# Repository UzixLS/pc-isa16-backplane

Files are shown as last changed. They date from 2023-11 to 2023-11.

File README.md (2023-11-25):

## ISA16-BACKPLANE
Compact ISA 16-bit backplane board

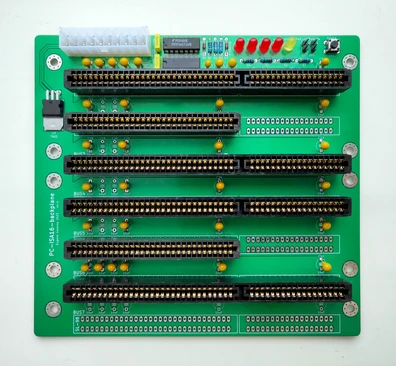
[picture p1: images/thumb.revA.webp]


Specs:
- 171x155mm
- 7 ISA 16-bit (98 pin) slots
- ATX 20 pin power supply connector
- ATX power control circuit
- LEDs for +5V, +12V, -5V, -12V and standby power rails
- Power button
- Headers for power button and +5V power led

### Changelog
* Rev.A - first release
* Rev.A1 - ATX connector changed from 5.5mm to 4.4mm and rotated 180°

### See also
* ISA 8-bit backplane by Sergey Kiselev: [link](https://github.com/skiselev/isa8_backplane)
* ISA 16-bit backplane by Alexandru Groza: [link](https://alexandrugroza.ro/microelectronics/system-design/isa-backplane/index.html)

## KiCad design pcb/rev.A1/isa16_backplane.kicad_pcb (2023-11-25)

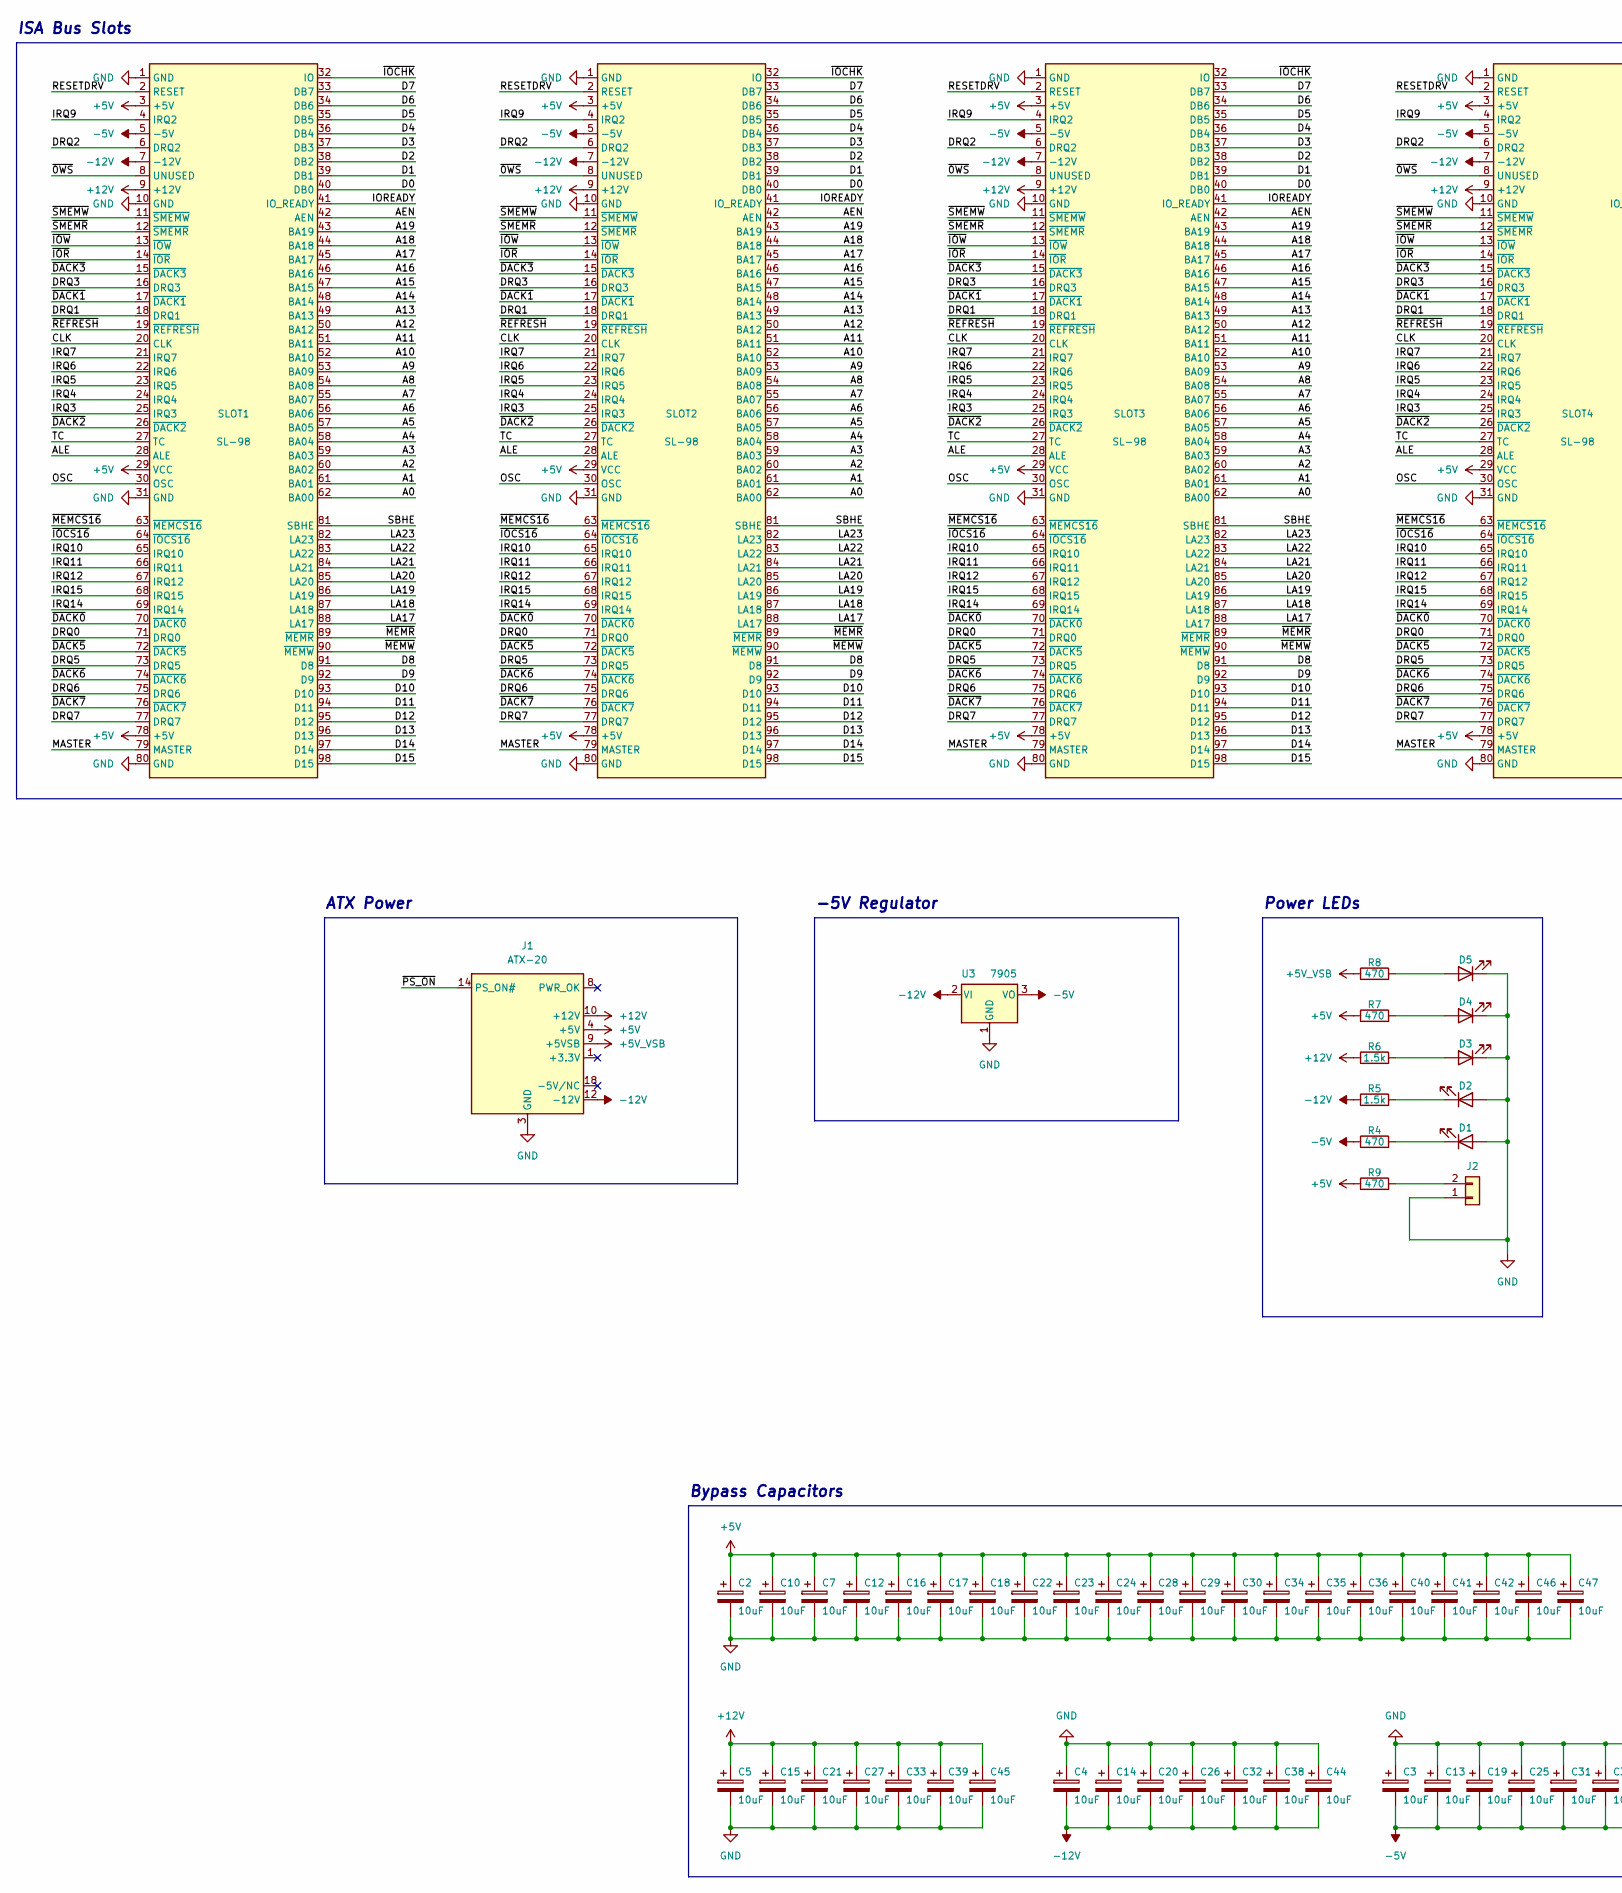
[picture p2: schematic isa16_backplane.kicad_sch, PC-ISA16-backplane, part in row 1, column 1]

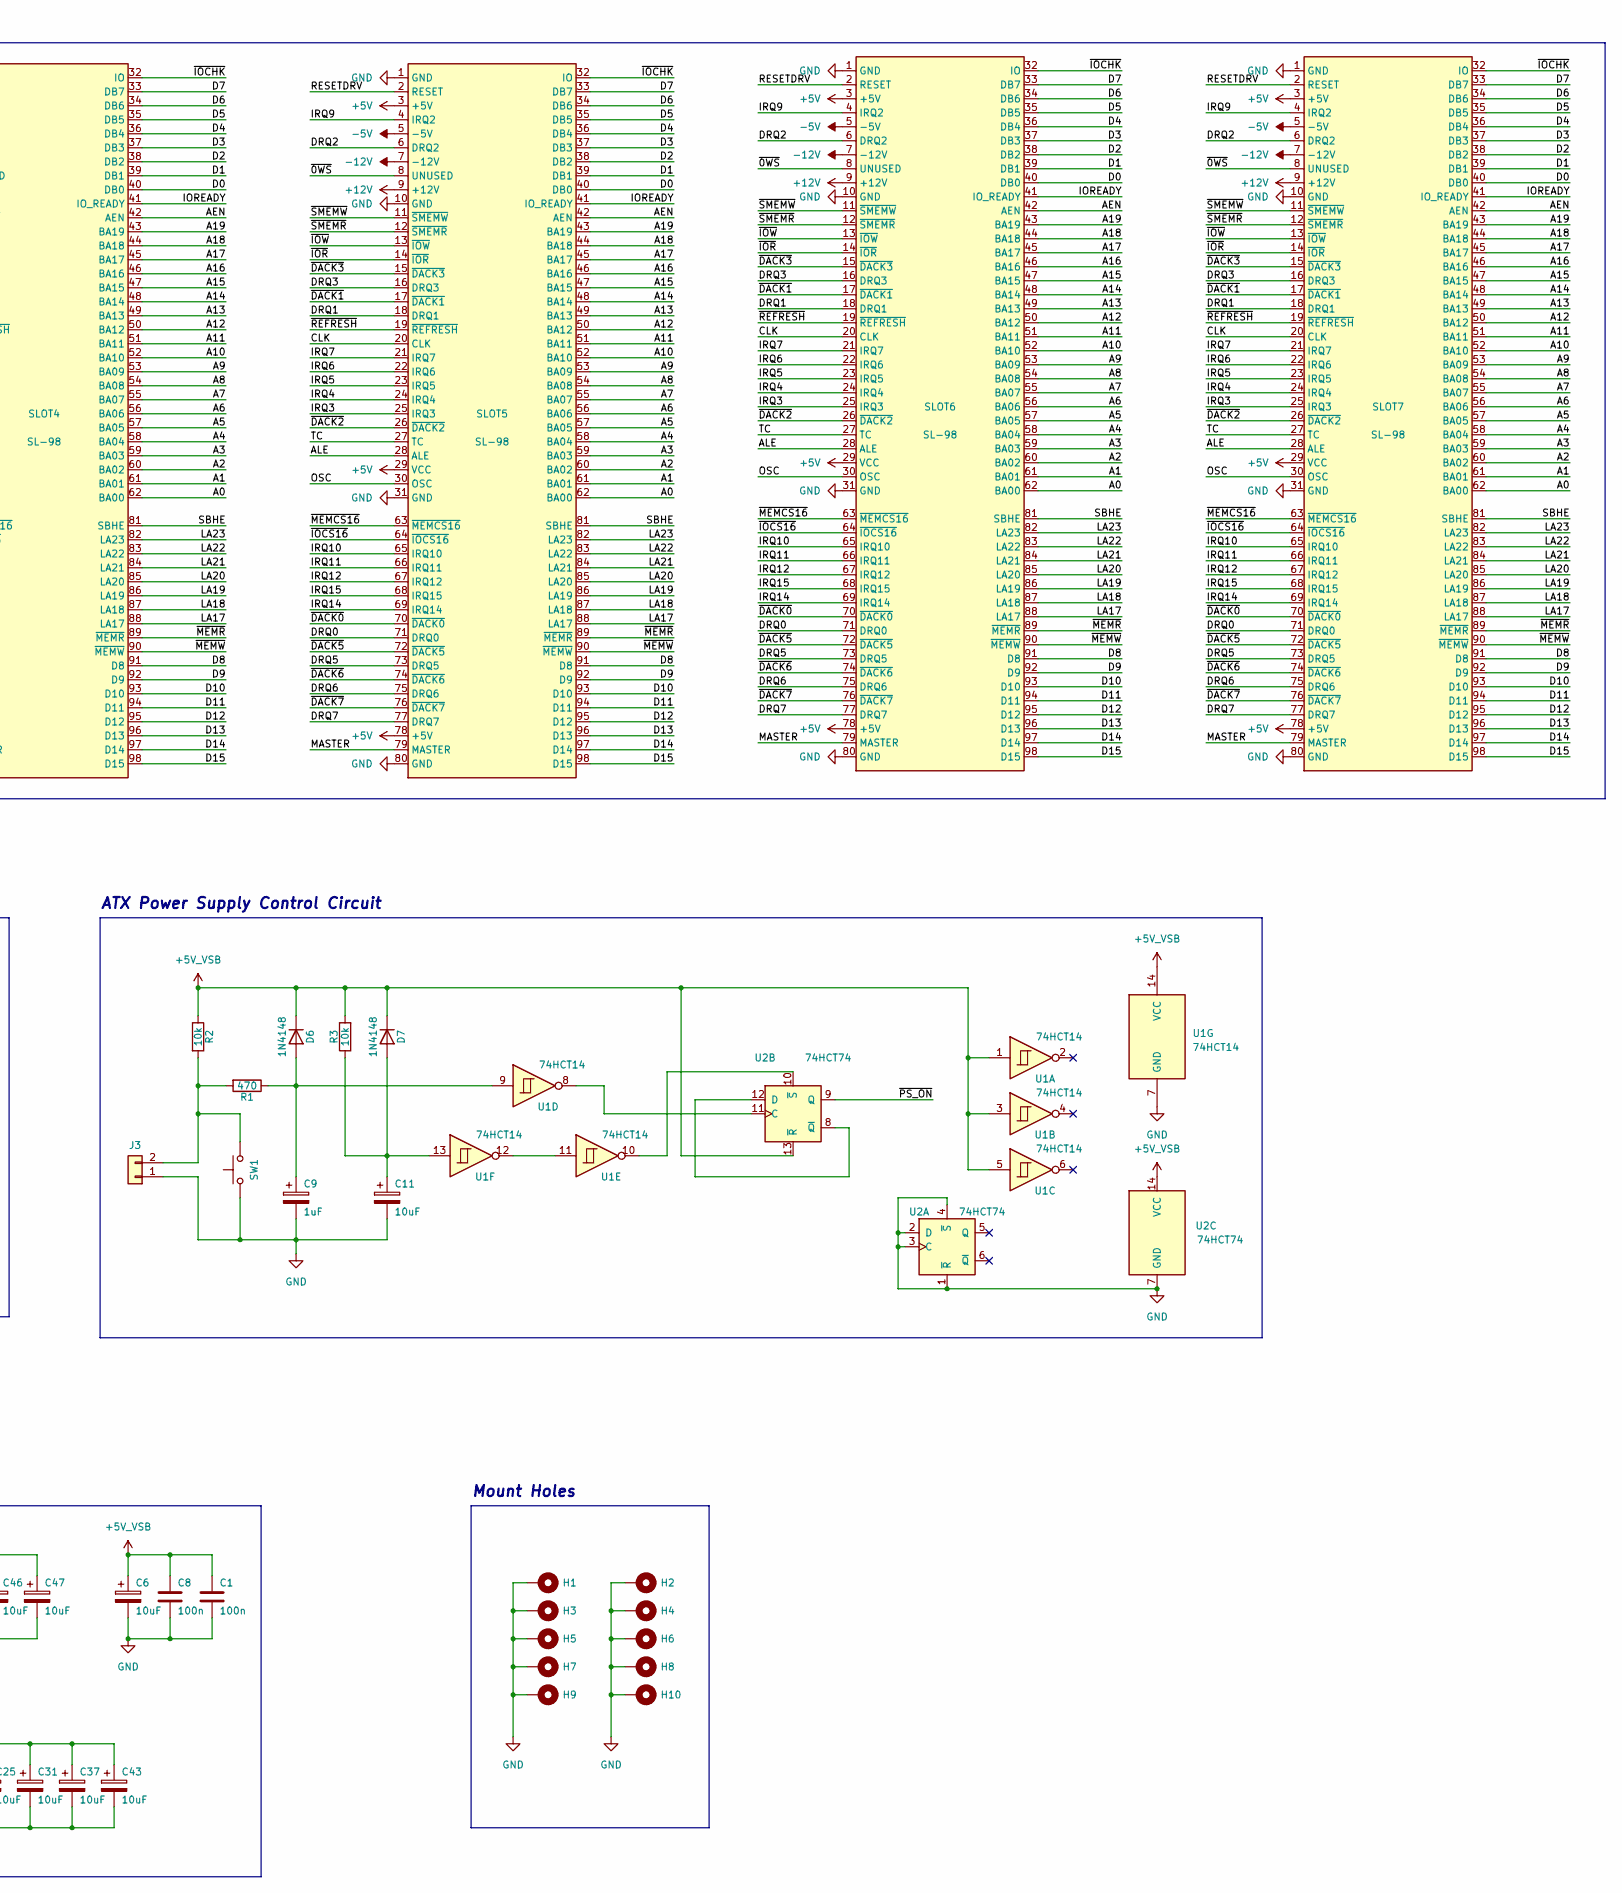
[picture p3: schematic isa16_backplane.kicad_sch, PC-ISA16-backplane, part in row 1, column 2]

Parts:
C1, C8: 100n; C_Disc_D8.0mm_W2.5mm_P5.00mm
C2, C3, C4, C5, C6, C7, C10, C11, C12, C13, C14, C15, C16, C17, C18, C19, C20, C21, C22, C23, C24, C25, C26, C27, C28, C29, C30, C31, C32, C33, C34, C35, C36, C37, C38, C39, C40, C41, C42, C43, C44, C45, C46, C47: 10uF; CP_Radial_Tantal_D5.0mm_P5.00mm
C9: 1uF; CP_Radial_Tantal_D5.0mm_P5.00mm
D1, D2, D3, D4, D5: LED; LED_D5.0mm
D6, D7: 1N4148; D_DO-35_SOD27_P7.62mm_Horizontal
H1, H2, H3, H4, H5, H6, H7, H8, H9, H10: MountingHole_Pad; MountingHole_4mm_Pad_Via
J1: ATX-20; Conn_Power_ATX_20pin_4.4mm
J2, J3: Conn_01x02; PinHeader_1x02_P2.54mm_Vertical
R1, R4, R7, R8, R9: 470; R_Axial_DIN0207_L6.3mm_D2.5mm_P7.62mm_Horizontal
R2, R3: 10k; R_Axial_DIN0207_L6.3mm_D2.5mm_P7.62mm_Horizontal
R5, R6: 1.5k; R_Axial_DIN0207_L6.3mm_D2.5mm_P7.62mm_Horizontal
SLOT1, SLOT2, SLOT3, SLOT4, SLOT5, SLOT6, SLOT7: SL-98; ISA16_Slot
SW1: SW_Push; SW_PUSH_6mm
U1: 74HCT14; DIP-14_W7.62mm
U2: 74HCT74; DIP-14_W7.62mm
U3: 7905; TO-220-3_Horizontal_TabDownPin2

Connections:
+5V: C2.1, C7.1, C10.1, C12.1, C16.1, C17.1, C18.1, C22.1, C23.1, C24.1, C28.1, C29.1, C30.1, C34.1, C35.1, C36.1, C40.1, C41.1, C42.1, C46.1, C47.1, J1.4 (+5V), J1.6 (+5V), J1.19 (+5V), J1.20 (+5V), R7.1, R9.1, SLOT1.3 (+5V), SLOT1.29 (VCC), SLOT1.78 (+5V), SLOT2.3 (+5V), SLOT2.29 (VCC), SLOT2.78 (+5V), SLOT3.3 (+5V), SLOT3.29 (VCC), SLOT3.78 (+5V), SLOT4.3 (+5V), SLOT4.29 (VCC), SLOT4.78 (+5V), SLOT5.3 (+5V), SLOT5.29 (VCC), SLOT5.78 (+5V), SLOT6.3 (+5V), SLOT6.29 (VCC), SLOT6.78 (+5V), SLOT7.3 (+5V), SLOT7.29 (VCC), SLOT7.78 (+5V)
+5V_VSB: C1.1, C6.1, C8.1, D6.1 (K), D7.1 (K), J1.9 (+5VSB), R2.1, R3.2, R8.1, U1.1, U1.3, U1.5, U1.14 (VCC), U2.13 (~R), U2.14 (VCC)
+12V: C5.1, C15.1, C21.1, C27.1, C33.1, C39.1, C45.1, J1.10 (+12V), R6.1, SLOT1.9 (+12V), SLOT2.9 (+12V), SLOT3.9 (+12V), SLOT4.9 (+12V), SLOT5.9 (+12V), SLOT6.9 (+12V), SLOT7.9 (+12V)
-5V: C3.2, C13.2, C19.2, C25.2, C31.2, C37.2, C43.2, R4.1, SLOT1.5 (-5V), SLOT2.5 (-5V), SLOT3.5 (-5V), SLOT4.5 (-5V), SLOT5.5 (-5V), SLOT6.5 (-5V), SLOT7.5 (-5V), U3.3 (VO)
-12V: C4.2, C14.2, C20.2, C26.2, C32.2, C38.2, C44.2, J1.12 (-12V), R5.1, SLOT1.7 (-12V), SLOT2.7 (-12V), SLOT3.7 (-12V), SLOT4.7 (-12V), SLOT5.7 (-12V), SLOT6.7 (-12V), SLOT7.7 (-12V), U3.2 (VI)
/A0: SLOT1.62 (BA00), SLOT2.62 (BA00), SLOT3.62 (BA00), SLOT4.62 (BA00), SLOT5.62 (BA00), SLOT6.62 (BA00), SLOT7.62 (BA00)
/A1: SLOT1.61 (BA01), SLOT2.61 (BA01), SLOT3.61 (BA01), SLOT4.61 (BA01), SLOT5.61 (BA01), SLOT6.61 (BA01), SLOT7.61 (BA01)
/A2: SLOT1.60 (BA02), SLOT2.60 (BA02), SLOT3.60 (BA02), SLOT4.60 (BA02), SLOT5.60 (BA02), SLOT6.60 (BA02), SLOT7.60 (BA02)
/A3: SLOT1.59 (BA03), SLOT2.59 (BA03), SLOT3.59 (BA03), SLOT4.59 (BA03), SLOT5.59 (BA03), SLOT6.59 (BA03), SLOT7.59 (BA03)
/A4: SLOT1.58 (BA04), SLOT2.58 (BA04), SLOT3.58 (BA04), SLOT4.58 (BA04), SLOT5.58 (BA04), SLOT6.58 (BA04), SLOT7.58 (BA04)
/A5: SLOT1.57 (BA05), SLOT2.57 (BA05), SLOT3.57 (BA05), SLOT4.57 (BA05), SLOT5.57 (BA05), SLOT6.57 (BA05), SLOT7.57 (BA05)
/A6: SLOT1.56 (BA06), SLOT2.56 (BA06), SLOT3.56 (BA06), SLOT4.56 (BA06), SLOT5.56 (BA06), SLOT6.56 (BA06), SLOT7.56 (BA06)
/A7: SLOT1.55 (BA07), SLOT2.55 (BA07), SLOT3.55 (BA07), SLOT4.55 (BA07), SLOT5.55 (BA07), SLOT6.55 (BA07), SLOT7.55 (BA07)
/A8: SLOT1.54 (BA08), SLOT2.54 (BA08), SLOT3.54 (BA08), SLOT4.54 (BA08), SLOT5.54 (BA08), SLOT6.54 (BA08), SLOT7.54 (BA08)
/A9: SLOT1.53 (BA09), SLOT2.53 (BA09), SLOT3.53 (BA09), SLOT4.53 (BA09), SLOT5.53 (BA09), SLOT6.53 (BA09), SLOT7.53 (BA09)
/A10: SLOT1.52 (BA10), SLOT2.52 (BA10), SLOT3.52 (BA10), SLOT4.52 (BA10), SLOT5.52 (BA10), SLOT6.52 (BA10), SLOT7.52 (BA10)
/A11: SLOT1.51 (BA11), SLOT2.51 (BA11), SLOT3.51 (BA11), SLOT4.51 (BA11), SLOT5.51 (BA11), SLOT6.51 (BA11), SLOT7.51 (BA11)
/A12: SLOT1.50 (BA12), SLOT2.50 (BA12), SLOT3.50 (BA12), SLOT4.50 (BA12), SLOT5.50 (BA12), SLOT6.50 (BA12), SLOT7.50 (BA12)
/A13: SLOT1.49 (BA13), SLOT2.49 (BA13), SLOT3.49 (BA13), SLOT4.49 (BA13), SLOT5.49 (BA13), SLOT6.49 (BA13), SLOT7.49 (BA13)
/A14: SLOT1.48 (BA14), SLOT2.48 (BA14), SLOT3.48 (BA14), SLOT4.48 (BA14), SLOT5.48 (BA14), SLOT6.48 (BA14), SLOT7.48 (BA14)
/A15: SLOT1.47 (BA15), SLOT2.47 (BA15), SLOT3.47 (BA15), SLOT4.47 (BA15), SLOT5.47 (BA15), SLOT6.47 (BA15), SLOT7.47 (BA15)
/A16: SLOT1.46 (BA16), SLOT2.46 (BA16), SLOT3.46 (BA16), SLOT4.46 (BA16), SLOT5.46 (BA16), SLOT6.46 (BA16), SLOT7.46 (BA16)
/A17: SLOT1.45 (BA17), SLOT2.45 (BA17), SLOT3.45 (BA17), SLOT4.45 (BA17), SLOT5.45 (BA17), SLOT6.45 (BA17), SLOT7.45 (BA17)
/A18: SLOT1.44 (BA18), SLOT2.44 (BA18), SLOT3.44 (BA18), SLOT4.44 (BA18), SLOT5.44 (BA18), SLOT6.44 (BA18), SLOT7.44 (BA18)
/A19: SLOT1.43 (BA19), SLOT2.43 (BA19), SLOT3.43 (BA19), SLOT4.43 (BA19), SLOT5.43 (BA19), SLOT6.43 (BA19), SLOT7.43 (BA19)
/AEN: SLOT1.42 (AEN), SLOT2.42 (AEN), SLOT3.42 (AEN), SLOT4.42 (AEN), SLOT5.42 (AEN), SLOT6.42 (AEN), SLOT7.42 (AEN)
/ALE: SLOT1.28 (ALE), SLOT2.28 (ALE), SLOT3.28 (ALE), SLOT4.28 (ALE), SLOT5.28 (ALE), SLOT6.28 (ALE), SLOT7.28 (ALE)
/CLK: SLOT1.20 (CLK), SLOT2.20 (CLK), SLOT3.20 (CLK), SLOT4.20 (CLK), SLOT5.20 (CLK), SLOT6.20 (CLK), SLOT7.20 (CLK)
/D0: SLOT1.40 (DB0), SLOT2.40 (DB0), SLOT3.40 (DB0), SLOT4.40 (DB0), SLOT5.40 (DB0), SLOT6.40 (DB0), SLOT7.40 (DB0)
/D1: SLOT1.39 (DB1), SLOT2.39 (DB1), SLOT3.39 (DB1), SLOT4.39 (DB1), SLOT5.39 (DB1), SLOT6.39 (DB1), SLOT7.39 (DB1)
/D2: SLOT1.38 (DB2), SLOT2.38 (DB2), SLOT3.38 (DB2), SLOT4.38 (DB2), SLOT5.38 (DB2), SLOT6.38 (DB2), SLOT7.38 (DB2)
/D3: SLOT1.37 (DB3), SLOT2.37 (DB3), SLOT3.37 (DB3), SLOT4.37 (DB3), SLOT5.37 (DB3), SLOT6.37 (DB3), SLOT7.37 (DB3)
/D4: SLOT1.36 (DB4), SLOT2.36 (DB4), SLOT3.36 (DB4), SLOT4.36 (DB4), SLOT5.36 (DB4), SLOT6.36 (DB4), SLOT7.36 (DB4)
/D5: SLOT1.35 (DB5), SLOT2.35 (DB5), SLOT3.35 (DB5), SLOT4.35 (DB5), SLOT5.35 (DB5), SLOT6.35 (DB5), SLOT7.35 (DB5)
/D6: SLOT1.34 (DB6), SLOT2.34 (DB6), SLOT3.34 (DB6), SLOT4.34 (DB6), SLOT5.34 (DB6), SLOT6.34 (DB6), SLOT7.34 (DB6)
/D7: SLOT1.33 (DB7), SLOT2.33 (DB7), SLOT3.33 (DB7), SLOT4.33 (DB7), SLOT5.33 (DB7), SLOT6.33 (DB7), SLOT7.33 (DB7)
/D8: SLOT1.91 (D8), SLOT2.91 (D8), SLOT3.91 (D8), SLOT4.91 (D8), SLOT5.91 (D8), SLOT6.91 (D8), SLOT7.91 (D8)
/D9: SLOT1.92 (D9), SLOT2.92 (D9), SLOT3.92 (D9), SLOT4.92 (D9), SLOT5.92 (D9), SLOT6.92 (D9), SLOT7.92 (D9)
/D10: SLOT1.93 (D10), SLOT2.93 (D10), SLOT3.93 (D10), SLOT4.93 (D10), SLOT5.93 (D10), SLOT6.93 (D10), SLOT7.93 (D10)
/D11: SLOT1.94 (D11), SLOT2.94 (D11), SLOT3.94 (D11), SLOT4.94 (D11), SLOT5.94 (D11), SLOT6.94 (D11), SLOT7.94 (D11)
/D12: SLOT1.95 (D12), SLOT2.95 (D12), SLOT3.95 (D12), SLOT4.95 (D12), SLOT5.95 (D12), SLOT6.95 (D12), SLOT7.95 (D12)
/D13: SLOT1.96 (D13), SLOT2.96 (D13), SLOT3.96 (D13), SLOT4.96 (D13), SLOT5.96 (D13), SLOT6.96 (D13), SLOT7.96 (D13)
/D14: SLOT1.97 (D14), SLOT2.97 (D14), SLOT3.97 (D14), SLOT4.97 (D14), SLOT5.97 (D14), SLOT6.97 (D14), SLOT7.97 (D14)
/D15: SLOT1.98 (D15), SLOT2.98 (D15), SLOT3.98 (D15), SLOT4.98 (D15), SLOT5.98 (D15), SLOT6.98 (D15), SLOT7.98 (D15)
/DRQ0: SLOT1.71 (DRQ0), SLOT2.71 (DRQ0), SLOT3.71 (DRQ0), SLOT4.71 (DRQ0), SLOT5.71 (DRQ0), SLOT6.71 (DRQ0), SLOT7.71 (DRQ0)
/DRQ1: SLOT1.18 (DRQ1), SLOT2.18 (DRQ1), SLOT3.18 (DRQ1), SLOT4.18 (DRQ1), SLOT5.18 (DRQ1), SLOT6.18 (DRQ1), SLOT7.18 (DRQ1)
/DRQ2: SLOT1.6 (DRQ2), SLOT2.6 (DRQ2), SLOT3.6 (DRQ2), SLOT4.6 (DRQ2), SLOT5.6 (DRQ2), SLOT6.6 (DRQ2), SLOT7.6 (DRQ2)
/DRQ3: SLOT1.16 (DRQ3), SLOT2.16 (DRQ3), SLOT3.16 (DRQ3), SLOT4.16 (DRQ3), SLOT5.16 (DRQ3), SLOT6.16 (DRQ3), SLOT7.16 (DRQ3)
/DRQ5: SLOT1.73 (DRQ5), SLOT2.73 (DRQ5), SLOT3.73 (DRQ5), SLOT4.73 (DRQ5), SLOT5.73 (DRQ5), SLOT6.73 (DRQ5), SLOT7.73 (DRQ5)
/DRQ6: SLOT1.75 (DRQ6), SLOT2.75 (DRQ6), SLOT3.75 (DRQ6), SLOT4.75 (DRQ6), SLOT5.75 (DRQ6), SLOT6.75 (DRQ6), SLOT7.75 (DRQ6)
/DRQ7: SLOT1.77 (DRQ7), SLOT2.77 (DRQ7), SLOT3.77 (DRQ7), SLOT4.77 (DRQ7), SLOT5.77 (DRQ7), SLOT6.77 (DRQ7), SLOT7.77 (DRQ7)
/IOREADY: SLOT1.41 (IO_READY), SLOT2.41 (IO_READY), SLOT3.41 (IO_READY), SLOT4.41 (IO_READY), SLOT5.41 (IO_READY), SLOT6.41 (IO_READY), SLOT7.41 (IO_READY)
/IRQ3: SLOT1.25 (IRQ3), SLOT2.25 (IRQ3), SLOT3.25 (IRQ3), SLOT4.25 (IRQ3), SLOT5.25 (IRQ3), SLOT6.25 (IRQ3), SLOT7.25 (IRQ3)
/IRQ4: SLOT1.24 (IRQ4), SLOT2.24 (IRQ4), SLOT3.24 (IRQ4), SLOT4.24 (IRQ4), SLOT5.24 (IRQ4), SLOT6.24 (IRQ4), SLOT7.24 (IRQ4)
/IRQ5: SLOT1.23 (IRQ5), SLOT2.23 (IRQ5), SLOT3.23 (IRQ5), SLOT4.23 (IRQ5), SLOT5.23 (IRQ5), SLOT6.23 (IRQ5), SLOT7.23 (IRQ5)
/IRQ6: SLOT1.22 (IRQ6), SLOT2.22 (IRQ6), SLOT3.22 (IRQ6), SLOT4.22 (IRQ6), SLOT5.22 (IRQ6), SLOT6.22 (IRQ6), SLOT7.22 (IRQ6)
/IRQ7: SLOT1.21 (IRQ7), SLOT2.21 (IRQ7), SLOT3.21 (IRQ7), SLOT4.21 (IRQ7), SLOT5.21 (IRQ7), SLOT6.21 (IRQ7), SLOT7.21 (IRQ7)
/IRQ9: SLOT1.4 (IRQ2), SLOT2.4 (IRQ2), SLOT3.4 (IRQ2), SLOT4.4 (IRQ2), SLOT5.4 (IRQ2), SLOT6.4 (IRQ2), SLOT7.4 (IRQ2)
/IRQ10: SLOT1.65 (IRQ10), SLOT2.65 (IRQ10), SLOT3.65 (IRQ10), SLOT4.65 (IRQ10), SLOT5.65 (IRQ10), SLOT6.65 (IRQ10), SLOT7.65 (IRQ10)
/IRQ11: SLOT1.66 (IRQ11), SLOT2.66 (IRQ11), SLOT3.66 (IRQ11), SLOT4.66 (IRQ11), SLOT5.66 (IRQ11), SLOT6.66 (IRQ11), SLOT7.66 (IRQ11)
/IRQ12: SLOT1.67 (IRQ12), SLOT2.67 (IRQ12), SLOT3.67 (IRQ12), SLOT4.67 (IRQ12), SLOT5.67 (IRQ12), SLOT6.67 (IRQ12), SLOT7.67 (IRQ12)
/IRQ14: SLOT1.69 (IRQ14), SLOT2.69 (IRQ14), SLOT3.69 (IRQ14), SLOT4.69 (IRQ14), SLOT5.69 (IRQ14), SLOT6.69 (IRQ14), SLOT7.69 (IRQ14)
/IRQ15: SLOT1.68 (IRQ15), SLOT2.68 (IRQ15), SLOT3.68 (IRQ15), SLOT4.68 (IRQ15), SLOT5.68 (IRQ15), SLOT6.68 (IRQ15), SLOT7.68 (IRQ15)
/LA17: SLOT1.88 (LA17), SLOT2.88 (LA17), SLOT3.88 (LA17), SLOT4.88 (LA17), SLOT5.88 (LA17), SLOT6.88 (LA17), SLOT7.88 (LA17)
/LA18: SLOT1.87 (LA18), SLOT2.87 (LA18), SLOT3.87 (LA18), SLOT4.87 (LA18), SLOT5.87 (LA18), SLOT6.87 (LA18), SLOT7.87 (LA18)
/LA19: SLOT1.86 (LA19), SLOT2.86 (LA19), SLOT3.86 (LA19), SLOT4.86 (LA19), SLOT5.86 (LA19), SLOT6.86 (LA19), SLOT7.86 (LA19)
/LA20: SLOT1.85 (LA20), SLOT2.85 (LA20), SLOT3.85 (LA20), SLOT4.85 (LA20), SLOT5.85 (LA20), SLOT6.85 (LA20), SLOT7.85 (LA20)
/LA21: SLOT1.84 (LA21), SLOT2.84 (LA21), SLOT3.84 (LA21), SLOT4.84 (LA21), SLOT5.84 (LA21), SLOT6.84 (LA21), SLOT7.84 (LA21)
/LA22: SLOT1.83 (LA22), SLOT2.83 (LA22), SLOT3.83 (LA22), SLOT4.83 (LA22), SLOT5.83 (LA22), SLOT6.83 (LA22), SLOT7.83 (LA22)
/LA23: SLOT1.82 (LA23), SLOT2.82 (LA23), SLOT3.82 (LA23), SLOT4.82 (LA23), SLOT5.82 (LA23), SLOT6.82 (LA23), SLOT7.82 (LA23)
/MASTER: SLOT1.79 (MASTER), SLOT2.79 (MASTER), SLOT3.79 (MASTER), SLOT4.79 (MASTER), SLOT5.79 (MASTER), SLOT6.79 (MASTER), SLOT7.79 (MASTER)
/OSC: SLOT1.30 (OSC), SLOT2.30 (OSC), SLOT3.30 (OSC), SLOT4.30 (OSC), SLOT5.30 (OSC), SLOT6.30 (OSC), SLOT7.30 (OSC)
/RESETDRV: SLOT1.2 (RESET), SLOT2.2 (RESET), SLOT3.2 (RESET), SLOT4.2 (RESET), SLOT5.2 (RESET), SLOT6.2 (RESET), SLOT7.2 (RESET)
/SBHE: SLOT1.81 (SBHE), SLOT2.81 (SBHE), SLOT3.81 (SBHE), SLOT4.81 (SBHE), SLOT5.81 (SBHE), SLOT6.81 (SBHE), SLOT7.81 (SBHE)
/TC: SLOT1.27 (TC), SLOT2.27 (TC), SLOT3.27 (TC), SLOT4.27 (TC), SLOT5.27 (TC), SLOT6.27 (TC), SLOT7.27 (TC)
/~0WS: SLOT1.8 (UNUSED), SLOT2.8 (UNUSED), SLOT3.8 (UNUSED), SLOT4.8 (UNUSED), SLOT5.8 (UNUSED), SLOT6.8 (UNUSED), SLOT7.8 (UNUSED)
/~DACK0: SLOT1.70 (~DACK0), SLOT2.70 (~DACK0), SLOT3.70 (~DACK0), SLOT4.70 (~DACK0), SLOT5.70 (~DACK0), SLOT6.70 (~DACK0), SLOT7.70 (~DACK0)
/~DACK1: SLOT1.17 (~DACK1), SLOT2.17 (~DACK1), SLOT3.17 (~DACK1), SLOT4.17 (~DACK1), SLOT5.17 (~DACK1), SLOT6.17 (~DACK1), SLOT7.17 (~DACK1)
/~DACK2: SLOT1.26 (~DACK2), SLOT2.26 (~DACK2), SLOT3.26 (~DACK2), SLOT4.26 (~DACK2), SLOT5.26 (~DACK2), SLOT6.26 (~DACK2), SLOT7.26 (~DACK2)
/~DACK3: SLOT1.15 (~DACK3), SLOT2.15 (~DACK3), SLOT3.15 (~DACK3), SLOT4.15 (~DACK3), SLOT5.15 (~DACK3), SLOT6.15 (~DACK3), SLOT7.15 (~DACK3)
/~DACK5: SLOT1.72 (~DACK5), SLOT2.72 (~DACK5), SLOT3.72 (~DACK5), SLOT4.72 (~DACK5), SLOT5.72 (~DACK5), SLOT6.72 (~DACK5), SLOT7.72 (~DACK5)
/~DACK6: SLOT1.74 (~DACK6), SLOT2.74 (~DACK6), SLOT3.74 (~DACK6), SLOT4.74 (~DACK6), SLOT5.74 (~DACK6), SLOT6.74 (~DACK6), SLOT7.74 (~DACK6)
/~DACK7: SLOT1.76 (~DACK7), SLOT2.76 (~DACK7), SLOT3.76 (~DACK7), SLOT4.76 (~DACK7), SLOT5.76 (~DACK7), SLOT6.76 (~DACK7), SLOT7.76 (~DACK7)
/~IOCHK: SLOT1.32 (IO), SLOT2.32 (IO), SLOT3.32 (IO), SLOT4.32 (IO), SLOT5.32 (IO), SLOT6.32 (IO), SLOT7.32 (IO)
/~IOCS16: SLOT1.64 (~IOCS16), SLOT2.64 (~IOCS16), SLOT3.64 (~IOCS16), SLOT4.64 (~IOCS16), SLOT5.64 (~IOCS16), SLOT6.64 (~IOCS16), SLOT7.64 (~IOCS16)
/~IOR: SLOT1.14 (~IOR), SLOT2.14 (~IOR), SLOT3.14 (~IOR), SLOT4.14 (~IOR), SLOT5.14 (~IOR), SLOT6.14 (~IOR), SLOT7.14 (~IOR)
/~IOW: SLOT1.13 (~IOW), SLOT2.13 (~IOW), SLOT3.13 (~IOW), SLOT4.13 (~IOW), SLOT5.13 (~IOW), SLOT6.13 (~IOW), SLOT7.13 (~IOW)
/~MEMCS16: SLOT1.63 (~MEMCS16), SLOT2.63 (~MEMCS16), SLOT3.63 (~MEMCS16), SLOT4.63 (~MEMCS16), SLOT5.63 (~MEMCS16), SLOT6.63 (~MEMCS16), SLOT7.63 (~MEMCS16)
/~MEMR: SLOT1.89 (~MEMR), SLOT2.89 (~MEMR), SLOT3.89 (~MEMR), SLOT4.89 (~MEMR), SLOT5.89 (~MEMR), SLOT6.89 (~MEMR), SLOT7.89 (~MEMR)
/~MEMW: SLOT1.90 (~MEMW), SLOT2.90 (~MEMW), SLOT3.90 (~MEMW), SLOT4.90 (~MEMW), SLOT5.90 (~MEMW), SLOT6.90 (~MEMW), SLOT7.90 (~MEMW)
/~PS_ON: J1.14 (PS_ON#), U2.9 (Q)
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

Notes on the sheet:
ATX Power Supply Control Circuit
Bypass Capacitors
Power LEDs
-5V Regulator
Mount Holes
ATX Power
ISA Bus Slots

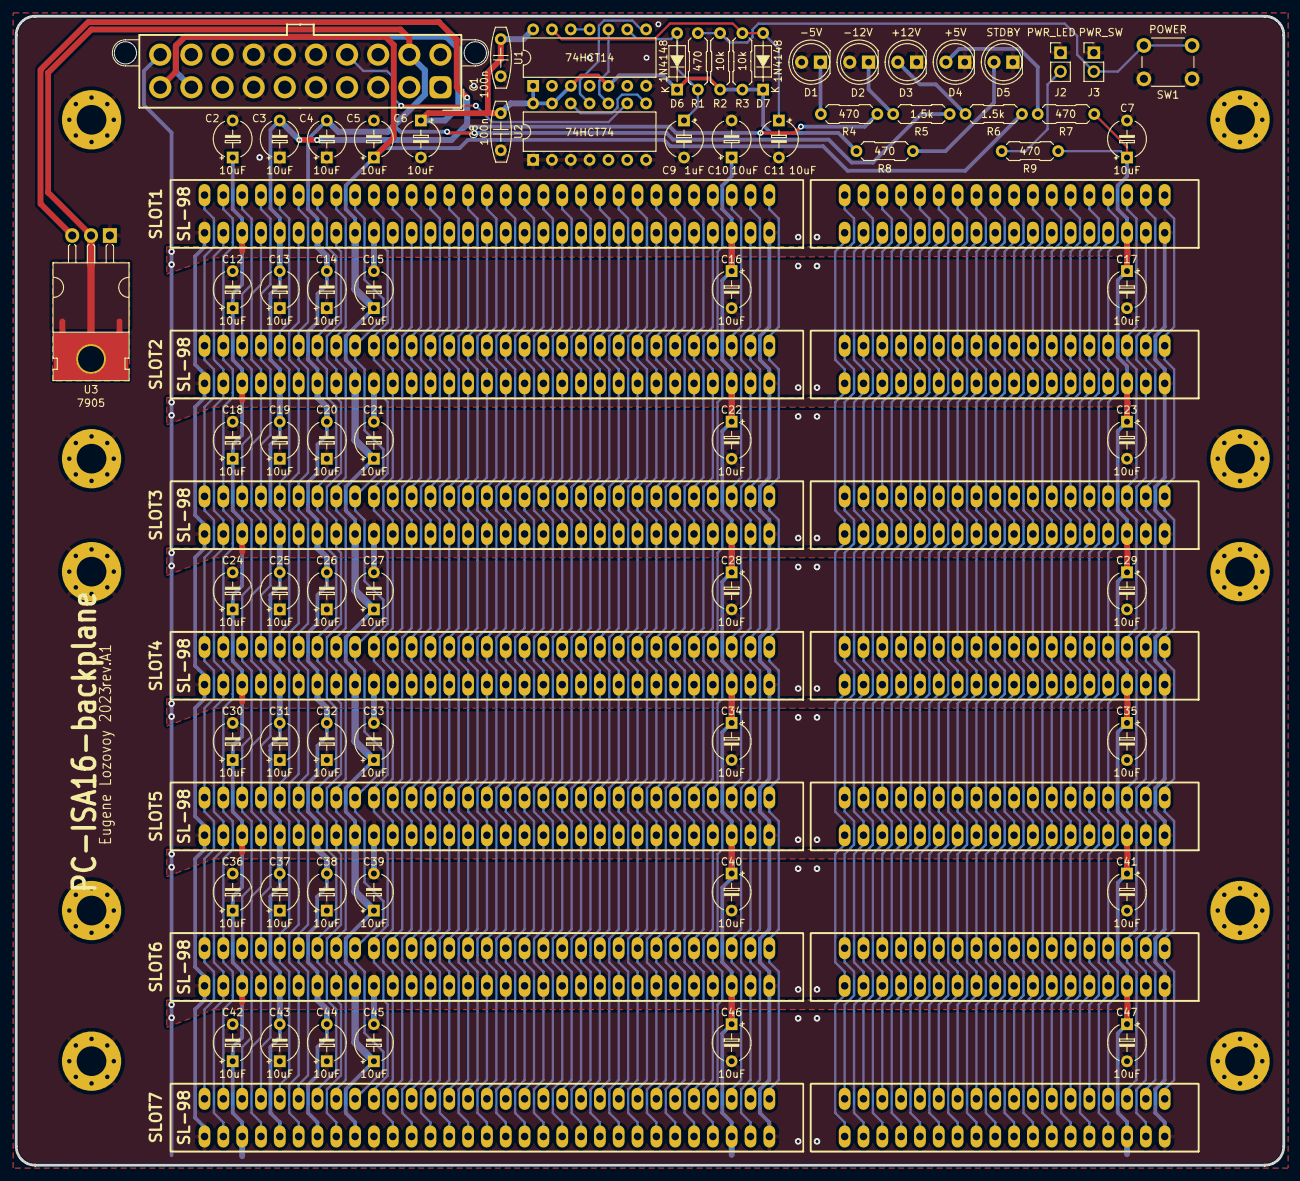
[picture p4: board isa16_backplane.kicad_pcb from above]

Board: 2 copper layers, 171.0 x 155.0 mm, 87 parts (0 on the bottom side), 108 nets.

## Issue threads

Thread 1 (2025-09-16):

Allow use of 24-pin ATX power connector

megatog615, 2025-09-16:
I am putting one of these boards together and noticed that it is quite hard to source 20-pin ATX connectors now. Maybe a separate version with a 24-pin connector could be made, shifting the connector to the left to accommodate the size and removing the screw hole.

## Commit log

2023-05-29 add pcb rev.A files (wip)
    [isa16_backplane.kicad_pcb, isa16_backplane.kicad_sch]
2023-11-17 update pcb rev.A files (final)
    [isa16_backplane.kicad_pcb, isa16_backplane.kicad_sch]
2023-11-17 add pcb rev.A1 files
    [isa16_backplane.kicad_pcb, isa16_backplane.kicad_sch]
2023-11-25 update pcb rev.A1 files (final)
    [isa16_backplane.kicad_pcb, isa16_backplane.kicad_sch]
2023-11-25 release pcb rev.A1
